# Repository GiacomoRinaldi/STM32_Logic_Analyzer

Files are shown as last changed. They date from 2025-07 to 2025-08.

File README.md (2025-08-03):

# STM32 Logic Analyzer

A versatile 4-channel logic analyzer built around the STM32F103 microcontroller, designed for analyzing digital communication protocols including I2C, SPI, and UART.

## Overview

This project implements a dual-mode logic analyzer capable of capturing and analyzing digital signals:

- **Polling Mode**: Continuously samples all 4 channels at regular intervals using DWT (Data Watchpoint and Trace) cycle counting for precise timing
- **Interrupt Mode**: Event-driven sampling that captures signal transitions (rising/falling edges) with timestamps, optimized for analyzing communication protocols

The device streams captured data over USB and includes Python scripts for visualization and protocol decoding.

### Circuit Shematic
<div align="center">
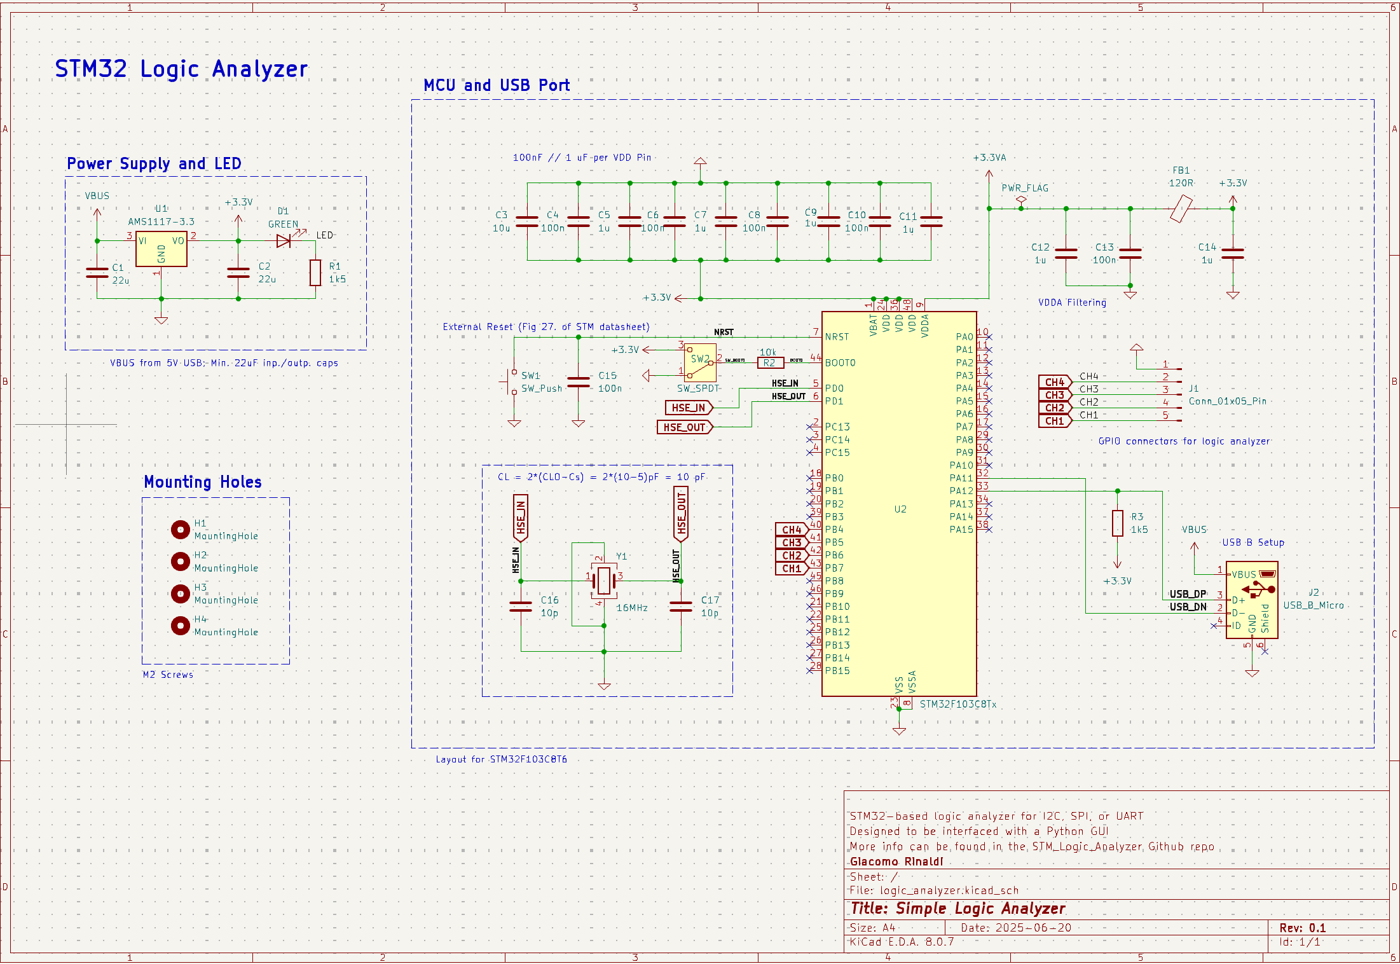
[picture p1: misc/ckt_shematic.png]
Circuit Schematic
  
</div>

### PCB Layout
<div align="center">
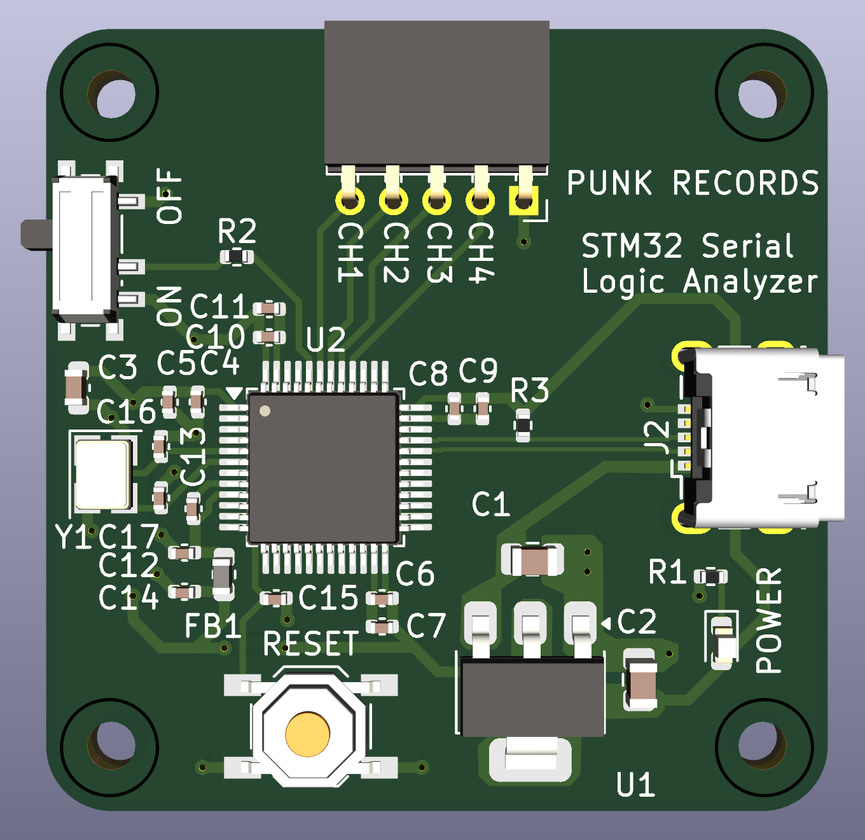
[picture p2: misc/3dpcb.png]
PCB Layout
  
</div>

### Device in Use
<table>
  <tr>
    <td>ckt_example</td>
    <td>trace_example</td>
  </tr>
  <tr>
    <td align="center">SPI Wiring</td>
    <td align="center">Example Trace</td>
  </tr>
</table>

### Current Work - 2nd Iteration of Device
<table>
  <tr>
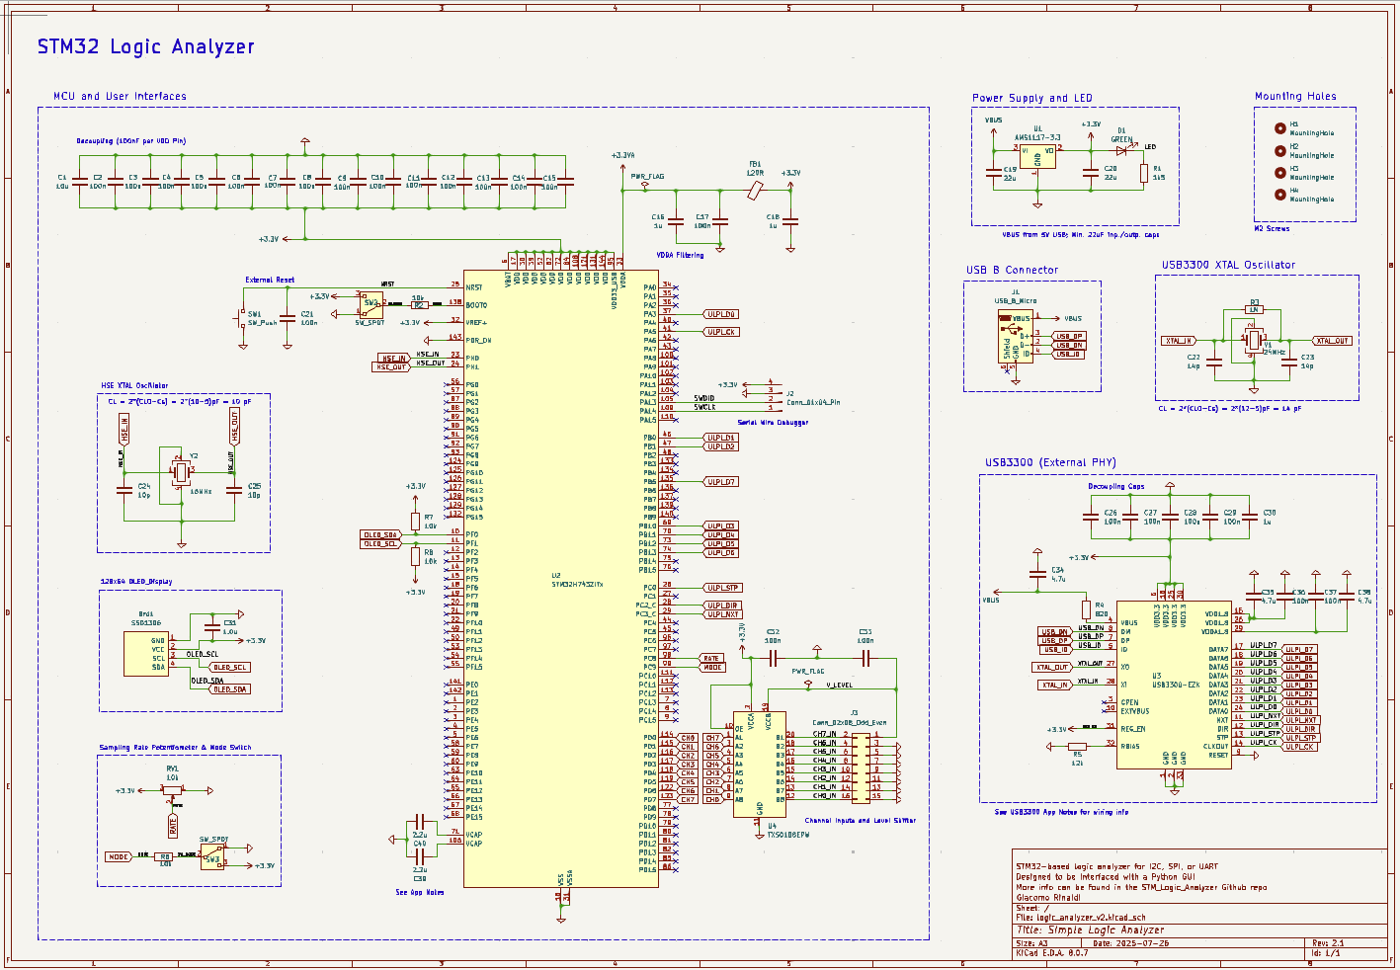
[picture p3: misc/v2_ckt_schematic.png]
v2_schematic
    <td></td>
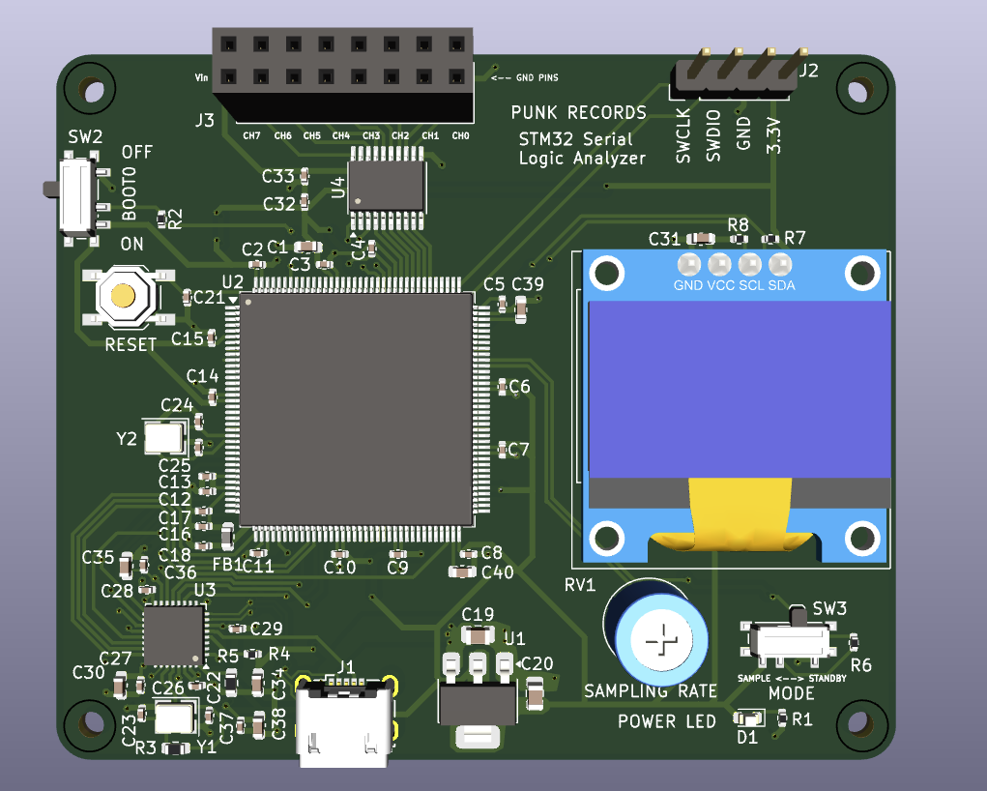
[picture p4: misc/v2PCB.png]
v2_PCB
    <td></td>
  </tr>
  <tr>
    <td align="center">V2.0 Circuit Schematic</td>
    <td align="center">V2.0 PCB</td>
  </tr>
</table>

## Features

- **4-Channel Digital Input**: Simultaneous monitoring of up to 4 digital signals
- **Dual Operating Modes**:
  - Polling mode for continuous sampling
  - Interrupt mode for edge-triggered event capture
- **Protocol Support**: Built-in decoding for I2C, SPI, and UART communication protocols
- **USB Connectivity**: Real-time data streaming via USB CDC (Virtual COM Port)
- **Python Integration**: Comprehensive plotting and decoding scripts for data analysis
- **High-Resolution Timing**: Utilizes STM32's DWT cycle counter and cascaded timers for precise timestamping
- **Efficient Data Handling**: Double-buffered data collection to minimize sample loss

## Hardware Specifications

- **MCU**: STM32F103 (72MHz ARM Cortex-M3)
- **Input Channels**: 4 channels (CH1-CH4) on pins PB4-PB7
- **Sample Rate**: Variable depending on mode
- **Data Interface**: USB 2.0 Full Speed
- **Power**: USB-powered
- **Input Voltage**: 3.3V logic levels

## Setup Instructions

### PCB Assembly
1. Order the PCB from JLCPCB using the production files in the `pcb_production_files/` folder
2. Solder components according to the provided schematic
3. Ensure proper USB connector installation for data communication

### Firmware Installation

**Option 1: SWD Programming**
1. Connect an ST-Link or compatible SWD programmer to the SWDIO and SCLK pins on the STM32F103
2. Flash the appropriate firmware binary (polling or interrupt mode)
3. Reset the device

**Option 2: DFU Bootloader**
1. Upload the bootloader from the `misc/` folder using SWD
2. Connect the device via USB
3. Use DFU utilities to upload the main firmware over USB

### Software Setup
1. Install Python dependencies for the analysis scripts
2. Connect the logic analyzer to your computer via USB
3. Connect target device signals to channels CH1-CH4
4. Run the Python plotting script to capture and visualize data
5. Use the decoding script to analyze communication protocols

### Usage Workflow
```bash
# 1. Capture data
python polling_plotter.py

# 2. Decode protocols
python polling_decoder.py
```

## Operating Modes

### Polling Mode
- Continuously samples all 4 channels at maximum rate
- Provides complete signal history with regular time intervals
- Best for analyzing continuous signals or unknown protocols
- Uses DWT cycle counter for precise timing
- Double-buffered operation prevents data loss during USB transmission

### Interrupt Mode
- Event-driven capture on signal transitions
- Efficient for sparse signals and protocol analysis
- Captures rising and falling edges with precise timestamps
- Uses cascaded TIM2/TIM3 timers for extended timing range
- Automatically shuts down after ~1.74 minutes to prevent timer overflow

## Data Format

### Polling Mode
```c
typedef struct {
    uint32_t timestamp;  // DWT cycle count
    uint8_t value;       // 4-bit channel states (PB4-PB7)
} Sample;
```

### Interrupt Mode
```
32-bit data format:
- Bit 31: Edge type (1=rising, 0=falling)
- Bits 30-29: Channel number (0-3)
- Bits 28-0: Timestamp (29-bit timer value)
```

## Python Scripts

The included Python scripts provide:
- **Data Visualization**: Real-time plotting of captured signals
- **Protocol Decoding**: Automatic analysis of I2C, SPI, and UART communications
- **Export Capabilities**: Save captured data in various formats
- **Customizable Analysis**: Modify scripts for specific protocols or requirements

## Development Plans

- **Hardware Upgrades**:
  - Migrate to higher-performance STM32 module with increased clock speed
  - Add external SRAM for larger capture buffers
  - Implement DMA-based USB transfers for improved throughput

- **Software Enhancements**:
  - Real-time protocol decoding during capture
  - Enhanced user interface for data visualization
  - Trigger functionality for complex capture scenarios

- **Performance Improvements**:
  - Optimize sampling rates and buffer management
  - Implement compression for longer capture sessions
  - Add hardware-based triggering capabilities

## Contributing

Contributions are welcome! Please feel free to submit issues, feature requests, or pull requests to improve the logic analyzer's functionality. This is an ongoing project that I plan to keep enhancing over time.

## Troubleshooting

- **Device not recognized**: Ensure USB drivers are properly installed
- **No data capture**: Verify connections to CH1-CH4 pins and signal voltage levels
- **Timing issues**: Check that target device and logic analyzer share common ground
- **Buffer overflow**: Reduce sampling rate or increase USB transfer frequency

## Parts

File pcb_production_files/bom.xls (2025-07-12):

Comment | Designator | Footprint | JLCPCB Part #
100n | C10,C13,C15,C4,C6,C8 | 0402 | C131394
120R | FB1 | 0603 | C85831
1u | C11,C12,C14,C5,C7,C9 | 0402 | C167339
16MHz | Y1 | Crystal_SMD_3225-4Pin_3.2x2.5mm | C133336
STM32F103C8Tx | U2 | LQFP-48_7x7mm_P0.5mm | C8734
10u | C3 | 0603 | C109457
USB_B_Micro | J2 | USB_Micro-B_Wuerth_629105150521 | C2894326
10k | R2 | 0402 | C471764
22u | C1,C2 | 0805 | C6119901
SW_SPDT | SW2 | SW_SPDT_PCM12 | C221841
GREEN | D1 | 0603 | C965806
SW_Push | SW1 | SW_SPST_TL3342 | C2886897
10p | C16,C17 | 0402 | C513437
AMS1117-3.3 | U1 | SOT-223-3_TabPin2 | C6186
1k5 | R1,R3 | 0402 | C114759

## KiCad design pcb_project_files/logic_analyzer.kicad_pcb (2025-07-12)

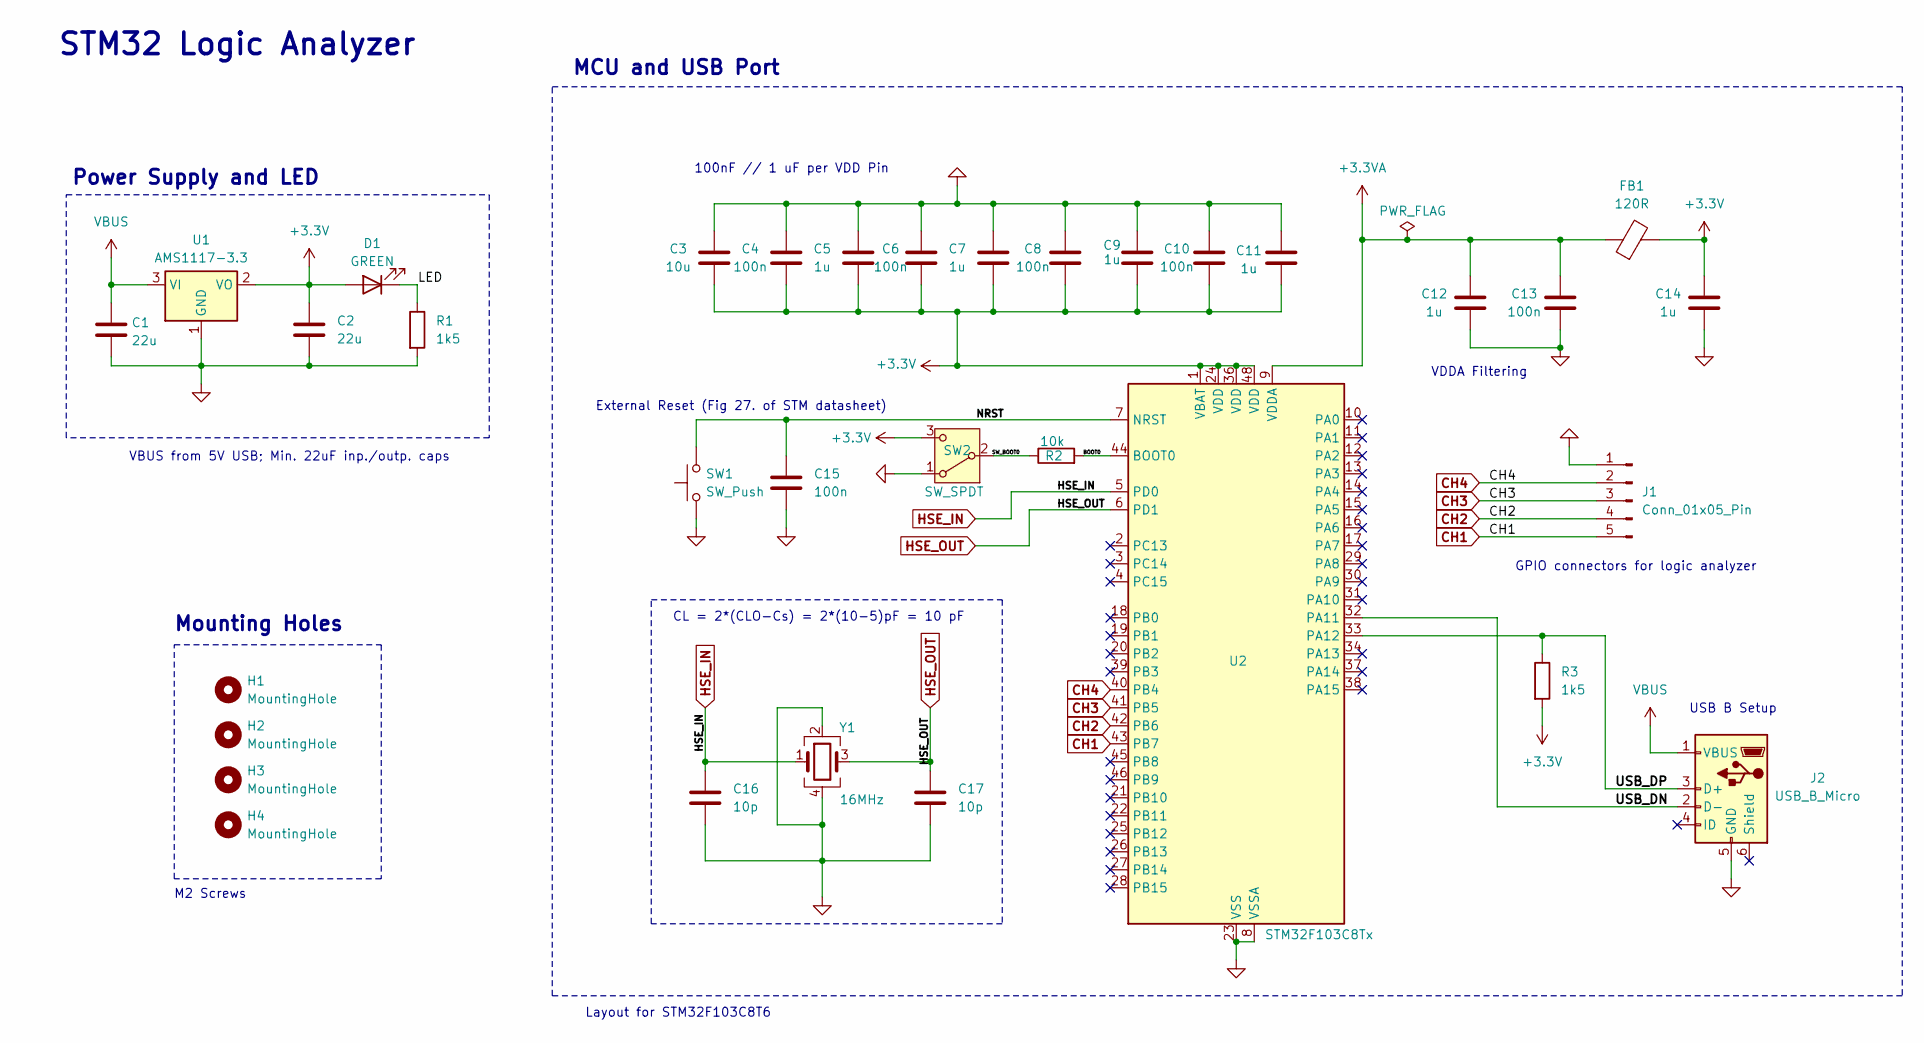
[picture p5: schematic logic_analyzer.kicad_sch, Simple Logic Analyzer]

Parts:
C1, C2: 22u; C_0805_2012Metric
C3: 10u; C_0603_1608Metric
C4, C6, C8, C10, C13, C15: 100n; C_0402_1005Metric
C5, C7, C9, C11, C12, C14: 1u; C_0402_1005Metric
C16, C17: 10p; C_0402_1005Metric
D1: GREEN; LED_0603_1608Metric
FB1: 120R; L_0603_1608Metric
H1, H2, H3, H4: MountingHole; MountingHole_2.2mm_M2
J1: Conn_01x05_Pin; PinSocket_1x05_P2.00mm_Horizontal
J2: USB_B_Micro; USB_Micro-B_Wuerth_629105150521
R1, R3: 1k5; R_0402_1005Metric
R2: 10k; R_0402_1005Metric
SW1: SW_Push; SW_SPST_TL3342
SW2: SW_SPDT; SW_SPDT_PCM12
U1: AMS1117-3.3; SOT-223-3_TabPin2
U2: STM32F103C8Tx; LQFP-48_7x7mm_P0.5mm
Y1: 16MHz; Crystal_SMD_3225-4Pin_3.2x2.5mm

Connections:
+3.3V: C2.1, C3.1, C4.1, C5.1, C6.1, C7.1, C8.1, C9.1, C10.1, C11.1, C14.2, D1.2 (A), FB1.2, R3.2, SW2.3 (C), U1.2 (VO), U2.1 (VBAT), U2.24 (VDD), U2.36 (VDD), U2.48 (VDD)
+3.3VA: C12.2, C13.2, FB1.1, U2.9 (VDDA)
/BOOT0: R2.2, U2.44 (BOOT0)
/LED: D1.1 (K), R1.1
/NRST: C15.1, SW1.2, U2.7 (NRST)
/SW_BOOT0: R2.1, SW2.2 (B)
/USB_DN: J2.2 (D-), U2.32 (PA11)
/USB_DP: J2.3 (D+), R3.1, U2.33 (PA12)
CH1: J1.5, U2.43 (PB7)
CH2: J1.4, U2.42 (PB6)
CH3: J1.3, U2.41 (PB5)
CH4: J1.2, U2.40 (PB4)
GND: C1.2, C2.2, C3.2, C4.2, C5.2, C6.2, C7.2, C8.2, C9.2, C10.2, C11.2, C12.1, C13.1, C14.1, C15.2, C16.2, C17.2, J1.1, J2.5 (GND), R1.2, SW1.1, SW2.1 (A), U1.1 (GND), U2.8 (VSSA), U2.23 (VSS), U2.35 (VSS), U2.47 (VSS), Y1.2, Y1.4
HSE_IN: C16.1, U2.5 (PD0), Y1.1
HSE_OUT: C17.1, U2.6 (PD1), Y1.3
VBUS: C1.1, J2.1 (VBUS), U1.3 (VI)

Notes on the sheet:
VBUS from 5V USB; Min. 22uF inp./outp. caps
100nF // 1 uF per VDD Pin
USB B Setup
External Reset (Fig 27. of STM datasheet)
M2 Screws
Power Supply and LED
CL = 2*(CLO-Cs) = 2*(10-5)pF = 10 pF
Layout for STM32F103C8T6
VDDA Filtering
Mounting Holes
GPIO connectors for logic analyzer
MCU and USB Port
STM32 Logic Analyzer

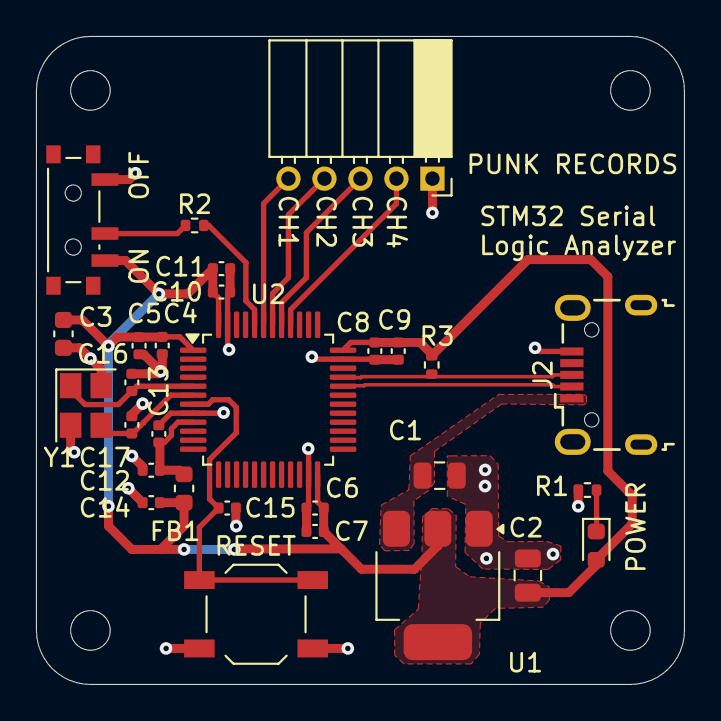
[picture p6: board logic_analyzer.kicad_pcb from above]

Board: 2 copper layers, 36.0 x 36.0 mm, 33 parts (0 on the bottom side), 16 nets.

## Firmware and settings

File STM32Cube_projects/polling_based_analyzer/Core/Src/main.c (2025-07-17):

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
/* Includes ------------------------------------------------------------------*/
#include "main.h"
#include "usb_device.h"

/* USER CODE BEGIN Includes */
#include "usbd_cdc_if.h"
/* USER CODE END Includes */

/* USER CODE BEGIN PTD */
typedef struct {
    uint32_t timestamp;
    uint8_t value;  // 4 bits: PB4–PB7
} __attribute__((__packed__)) Sample;

/* USER CODE END PTD */

/* USER CODE BEGIN PD */
#define SAMPLE_COUNT 1350  // Number of samples per buffer
#define BUFFER_SIZE  (SAMPLE_COUNT)
/* USER CODE END PD */


void SystemClock_Config(void);
static void MX_GPIO_Init(void);
/* USER CODE BEGIN 0 */
Sample bufferA[BUFFER_SIZE];
Sample bufferB[BUFFER_SIZE];
volatile uint8_t usingBufferA = 1;

void DWT_Init(void) {
    CoreDebug->DEMCR |= CoreDebug_DEMCR_TRCENA_Msk;
    DWT->CYCCNT = 0;
    DWT->CTRL |= DWT_CTRL_CYCCNTENA_Msk;
}

void send_buffer(Sample *buffer) {
    while (CDC_Transmit_FS((uint8_t*)buffer, sizeof(Sample) * BUFFER_SIZE) == USBD_BUSY);
}
/* USER CODE END 0 */

/**
  * @brief  The application entry point.
  * @retval int
  */
int main(void)
{

  /* MCU Configuration--------------------------------------------------------*/

  /* Reset of all peripherals, Initializes the Flash interface and the Systick. */
  HAL_Init();

  /* Configure the system clock */
  SystemClock_Config();

  /* Initialize all configured peripherals */
  MX_GPIO_Init();
  MX_USB_DEVICE_Init();
  /* USER CODE BEGIN 2 */
  DWT_Init();
  /* USER CODE END 2 */

  /* Infinite loop */
  /* USER CODE BEGIN WHILE */
  while (1)
  {
      Sample* current = usingBufferA ? bufferA : bufferB;

      for (int i = 0; i < SAMPLE_COUNT; i++) {
          current[i].timestamp = DWT->CYCCNT;
          current[i].value = (GPIOB->IDR >> 4) & 0x0F;
      }

      // Start USB transmit (non-blocking)
      send_buffer(current);

      // Switch buffers
      usingBufferA ^= 1;

    /* USER CODE END WHILE */

    /* USER CODE BEGIN 3 */
  }
  /* USER CODE END 3 */
}

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


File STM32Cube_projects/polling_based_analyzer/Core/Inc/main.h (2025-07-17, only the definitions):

#define HSE_IN_Pin GPIO_PIN_0
#define HSE_IN_GPIO_Port GPIOD
#define HSE_OUT_Pin GPIO_PIN_1
#define HSE_OUT_GPIO_Port GPIOD
#define USB_DN_Pin GPIO_PIN_11
#define USB_DN_GPIO_Port GPIOA
#define USB_DP_Pin GPIO_PIN_12
#define USB_DP_GPIO_Port GPIOA
#define CH4_Pin GPIO_PIN_4
#define CH4_GPIO_Port GPIOB
#define CH3_Pin GPIO_PIN_5
#define CH3_GPIO_Port GPIOB
#define CH2_Pin GPIO_PIN_6
#define CH2_GPIO_Port GPIOB
#define CH1_Pin GPIO_PIN_7
#define CH1_GPIO_Port GPIOB

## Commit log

2025-07-12 adding PCB project and production files
    [bom.xls, designators.csv, logic_analyzer.kicad_pcb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]
2025-07-12 created arduino tester file
2025-07-12 trying to get UART up and running
    [bitlog.csv]
2025-07-12 deleting bitlogging files
    [bitlog.csv]
2025-08-03 updating current work section

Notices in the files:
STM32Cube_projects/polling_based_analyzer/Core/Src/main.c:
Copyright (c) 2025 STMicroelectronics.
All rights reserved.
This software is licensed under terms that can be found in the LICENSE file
